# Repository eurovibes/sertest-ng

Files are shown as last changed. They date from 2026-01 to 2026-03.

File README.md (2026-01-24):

<!-- SPDX-FileCopyrightText: 2025 Benedikt Spranger <b.spranger@linutronix.de> -->
<!-- SPDX-License-Identifier: CERN-OHL-S-2.0 -->




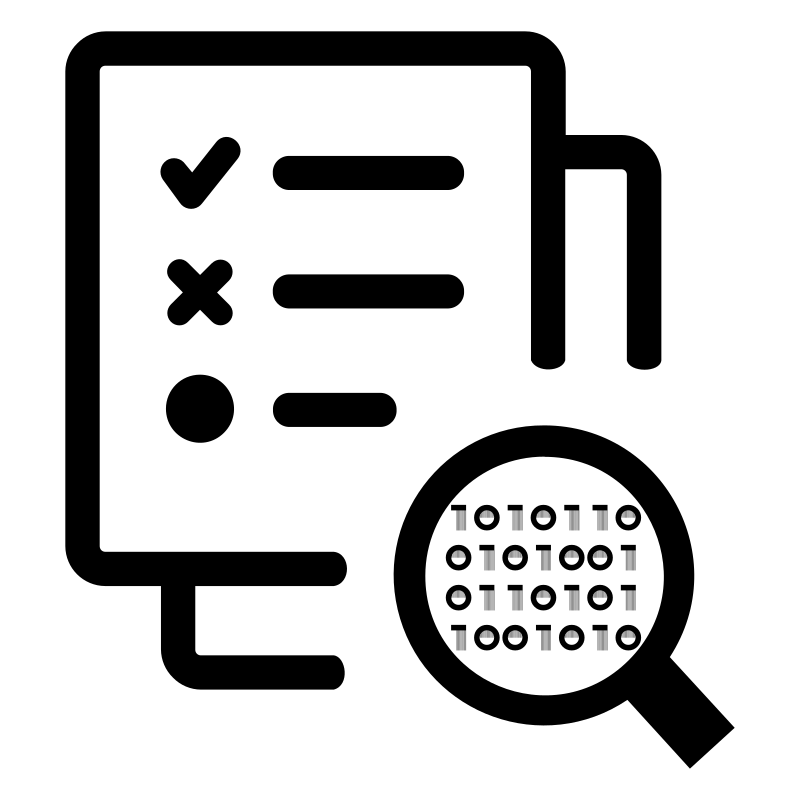
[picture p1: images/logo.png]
sertest-ng logo


# sertest-ng - A swiss knife serial testing tool

Serial interfaces like RS-232, RS-422/485 or CAN bus are even used in this
modern times. While reworking the 8250 driver in the Linux kernel jogness
faced plethora of nasty hardware dedication with modern serial hardware.
Single tasks overtop the banks in getting functional hardware. This sucks
and reliable full featured serial testing hardwaare is needed.

sertest-ng tries to fill that gap. It has a USB interface to control a
CAN/CAN-FD bus interface, a full featured RS-232 interface and a RS-422/485
interface. On top a RX/TX only RS-232 is equipped.

## License rules

sertest-ng is provided under the terms of the CERN-OHL-S license version 2 as
provided in the LICENSES/CERN-OHL-S-2.0 file.

Instead of adding license boilerplates to the individual files, sertest-ng uses
SPDX license identifiers, which are machine parseable and considered legaly
equivalent.

The SPDX license identifier in sertest-ng shall be added at the first possible
line in a file which can contain a comment. This is normally the first line
except for scripts. Scripts require the #!PATH_TO_INTERPRETER tag in the
first line; place the SPDX identifier into the second line.

The SPDX license identifier is added in form of a comment.

## Copyright and License
Copyright Benedikt Spranger 2025.
This source describes Open Hardware and is licensed under the CERNOHL-S v2.
You may redistribute and modify this source and make products using it
under the terms of the CERN-OHL-S v2
(https://ohwr.org/cern ohl_s_v2.txt).
This source is distributed WITHOUT ANY EXPRESS OR IMPLIED
WARRANTY, INCLUDING OF MERCHANTABILITY, SATISFACTORY
QUALITY AND FITNESS FOR A PARTICULAR PURPOSE. Please see
the CERN-OHL-S v2 for applicable conditions.
Source location: https://github.com/eurovibes/sertest-ng
As per CERN-OHL-S v2 section 4, should You produce hardware based
on this source, You must where practicable maintain the Source Location
visible on the external case of the sertest-ng or other products you make using
this source.

# Dedication
This hardware is dedicated to the great Linux Kernel Crew at Linutronix (https://www.linutronix.de)

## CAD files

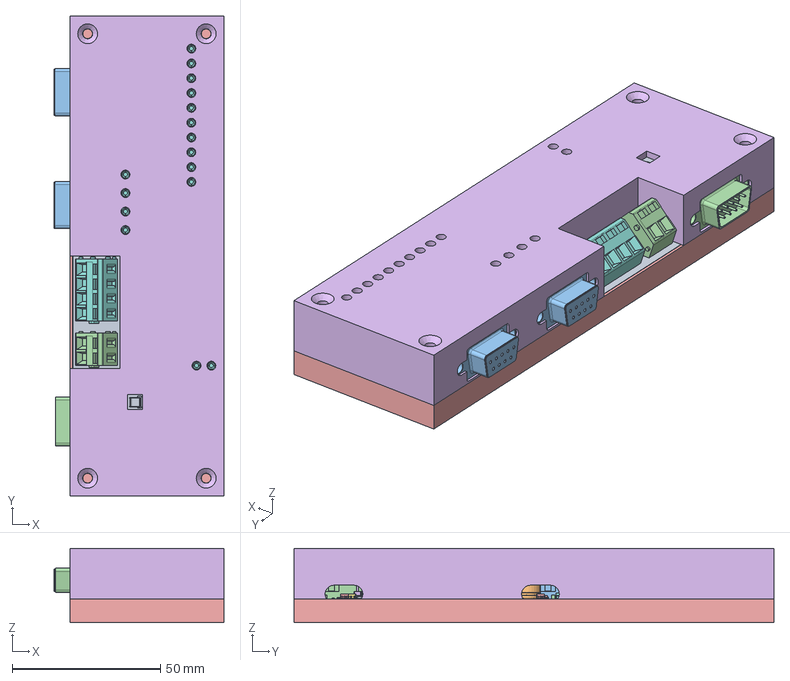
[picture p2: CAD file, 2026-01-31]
enclosure/sertest-ng.FCStd
57.3 x 162.0 x 25.0 mm
Pcb_c90
R209_R_0402_1005Metric_71b30412e50a x 52
SW101_SW_PUSH_6mm_52e52971358b
U202_TSSOP-24_4.4x7.8mm_P0.65mm_9c6549b88e3d
U303_SOT-23-6_ea51964c7aec x 2
D106_LED_0603_1608Metric_be7acdb3c4a0 x 6
C201_C_0402_1005Metric_272abea8df1f x 23
D211_AAA3528_c9d753128b57 x 16
R102_R_1206_3216Metric_2003ceb36cc6 x 3
U201_SSOP-28_5.3x10.2mm_P0.65mm_6feaa2b9f8e5
U103_LQFP-64_10x10mm_P0.5mm_cab5baf1425d
FB401_L_0805_2012Metric_7463febe9e80 x 6
D101_D_SOD-323_47d894987f89
U102_SOT-223_5101afb0bdb3
Y102_Crystal_SMD_3215-2Pin_3.2x1.5mm_ec3cd09e3611
J203_236-404_e90f42bb17cb
C302_C_0603_1608Metric_b7eb0275197c x 2
C110_C_0805_2012Metric_42e2c4361067 x 3
J201_DSUB-9_Socket_Horizontal_P2.77x2.84mm_EdgePinOffset4.94mm_Housed_ MountingHolesOffset4.94mm_27f627229b8b x 2
J401_DSUB-9_Pins_Horizontal_P2.77x2.84mm_EdgePinOffset4.94mm_Housed_ MountingHolesOffset4.94mm_41fe26cd4ce2
U101_SOIC-8_3.9x4.9mm_P1.27mm_d6df2d891575 x 2
JP403_PinHeader_1x02_P254mm_Vertical_ba5a3424f0d6
U302_JEITA_SOIC-8_3.9x4.9mm_P1.27mm_1356cbc908f0
U301_SOT-23-3_202f0379b9ee
SW401_TL2202xxYA_989cfd24e9e1
C106_CP_Radial_D80mm_P350mm_9079e7fa1cdd
Y101_Crystal_SMD_5032-2Pin_5.0x3.2mm_d8392e121ffc
J402_236-402_7fcaa99cd5cf
bottom
top

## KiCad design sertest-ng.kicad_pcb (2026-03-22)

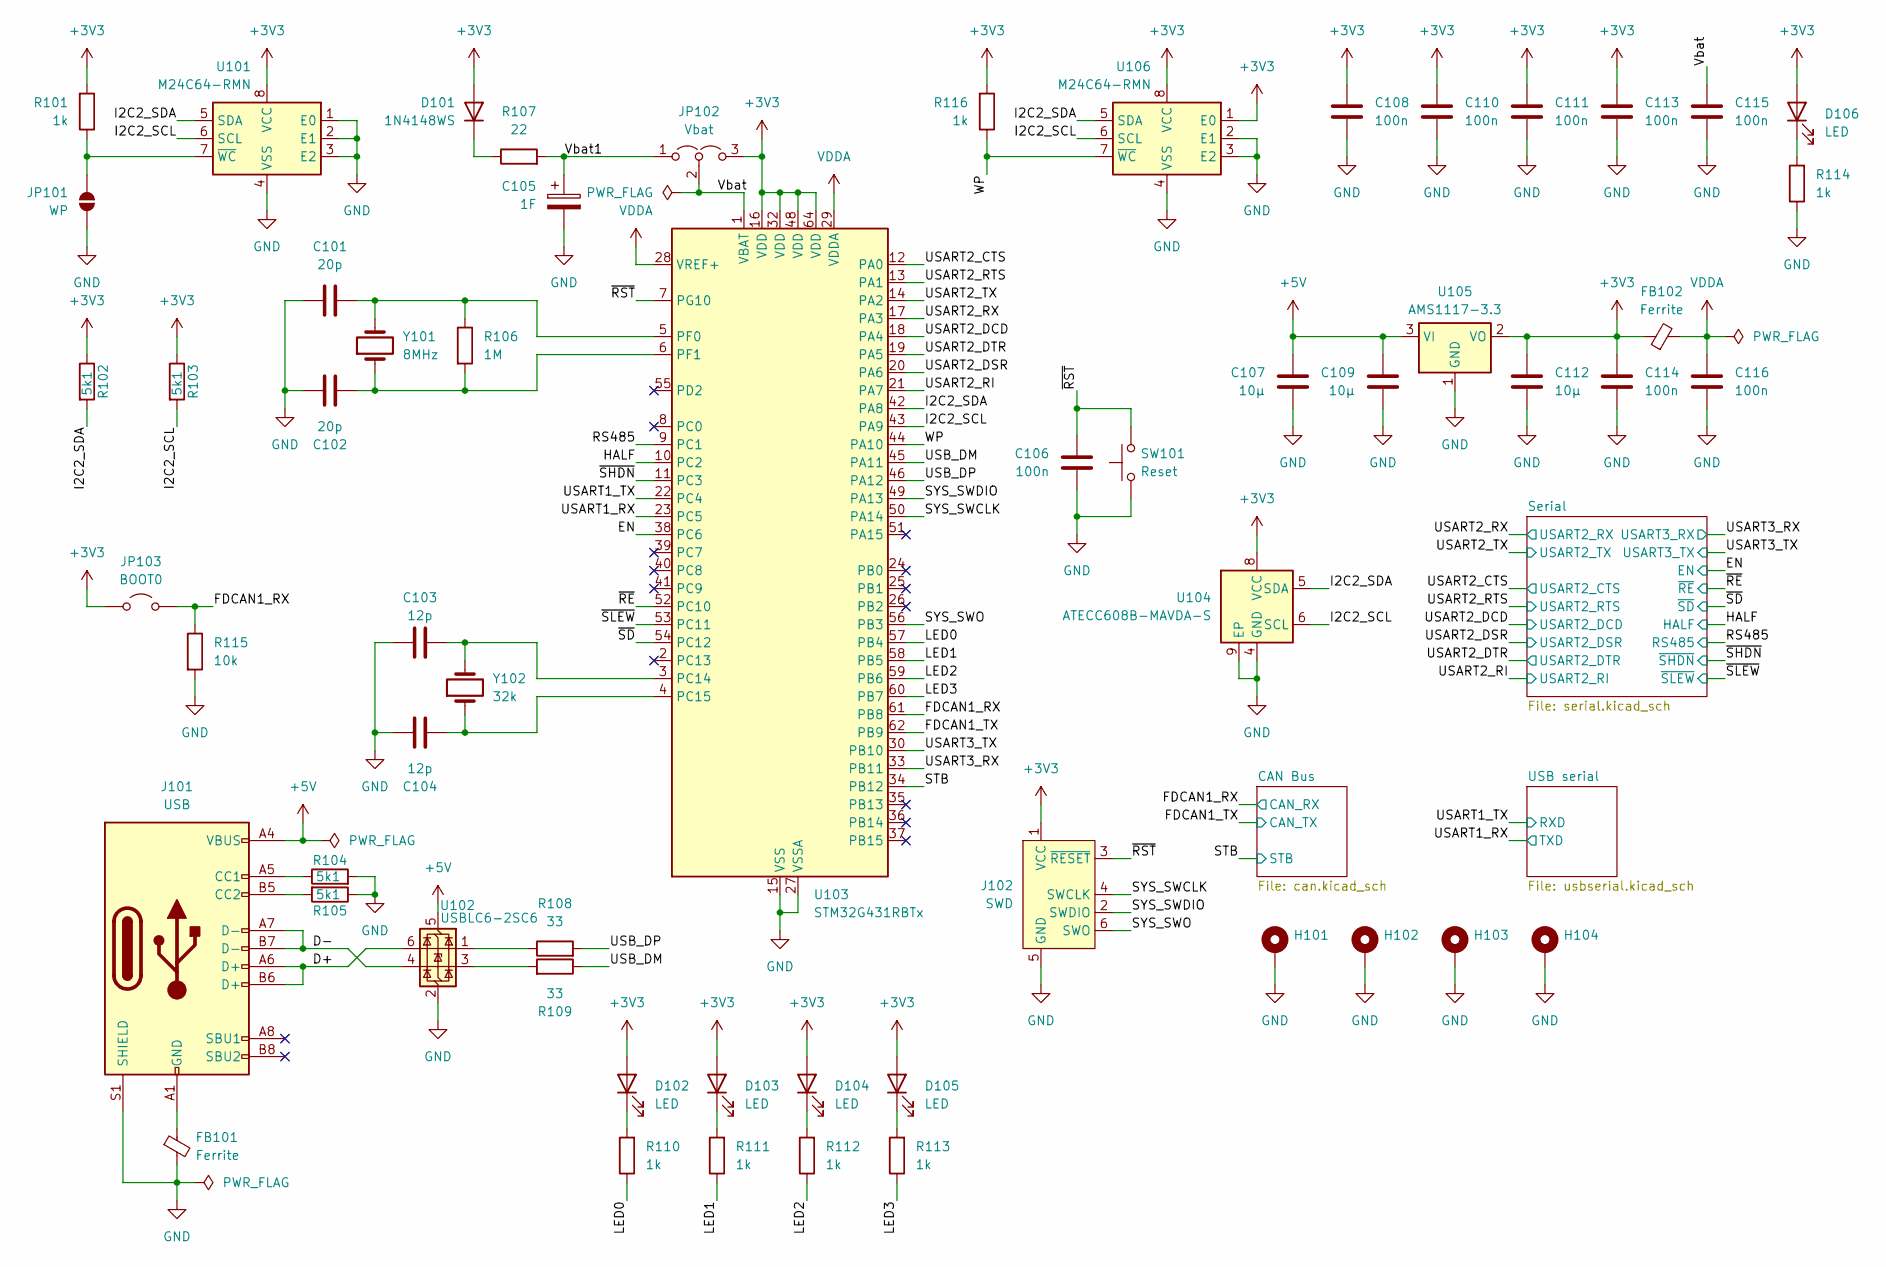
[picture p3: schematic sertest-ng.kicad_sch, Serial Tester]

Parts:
C101, C102: 20p; C_0402_1005Metric; lcsc# C1554
C103, C104: 12p; C_0402_1005Metric; lcsc# C1547
C105: 1F; CP_Radial_D8.0mm_P3.50mm
C106: 100n; C_0402_1005Metric; mpn CL05B104KB54PNC; LCSC# C307331
C107, C109, C112: 10µ; C_0805_2012Metric; lcsc# C15850
C108, C110, C111, C113, C114, C115, C116: 100n; C_0402_1005Metric; lcsc# C307331
D101: 1N4148WS; D_SOD-323; lcsc# C2128
D102, D103, D104, D105, D106: LED; LED_0603_1608Metric; mpn KT-0603R; LCSC# C2286
FB101: Ferrite; L_0805_2012Metric; mpn GZ1608D601TF; LCSC# C1002
FB102: Ferrite; L_0805_2012Metric; lcsc# C1015
H101, H102, H103, H104: MountingHole_3.2mm_M3_ISO14580_Pad; mpn N/A
J101: USB; USB_C_Receptacle_G-Switch_GT-USB-7010ASV; lcsc# C2988369
J102: SWD; Tag-Connect_TC2030-IDC-FP_2x03_P1.27mm_Vertical
JP101: WP; SolderJumper-2_P1.3mm_Open_Pad1.0x1.5mm
JP102: Vbat; SolderJumper-3_P1.3mm_Open_Pad1.0x1.5mm
JP103: BOOT0; SolderJumper-2_P1.3mm_Open_Pad1.0x1.5mm
R101, R110, R111, R112, R113, R114, R116: 1k; R_0402_1005Metric; mpn 0402WGF1001TCE; LCSC# C11702
R102, R103, R104, R105: 5k1; R_0402_1005Metric; lcsc# C25905
R106: 1M; R_0402_1005Metric; lcsc# C26083
R107: 22; R_1206_3216Metric; lcsc# C17958
R108, R109: 33; R_0402_1005Metric; lcsc# C25105
R115: 10k; R_0402_1005Metric; lcsc# C25744
SW101: Reset; SW_PUSH_6mm; mpn TACT-65R-F
U101, U106: M24C64-RMN; SOIC-8_3.9x4.9mm_P1.27mm; lcsc# C79988
U102: USBLC6-2SC6; SOT-23-6; mpn USBLC6-2SC6; LCSC# C2827654
U103: STM32G431RBTx; LQFP-64_10x10mm_P0.5mm; lcsc# C431633
U104: ATECC608B-MAVDA-S; DFN-8-1EP_3x2mm_P0.5mm_EP1.3x1.5mm; mpn ATECC608B-MAVDA-S; LCSC# C17350254
U105: AMS1117-3.3; SOT-223-3_TabPin2; lcsc# C6186
Y101: 8MHz; Crystal_SMD_5032-2Pin_5.0x3.2mm; lcsc# C115962
Y102: 32k; Crystal_SMD_3215-2Pin_3.2x1.5mm; lcsc# C32346

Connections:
+3V3: C108.1, C110.1, C111.1, C112.1, C113.1, C114.1, D101.2 (A), D102.2 (A), D103.2 (A), D104.2 (A), D105.2 (A), D106.2 (A), FB102.1, J102.1 (VCC), JP102.3 (B), JP103.1 (A), R101.2, R102.1, R103.1, R116.2, U101.8 (VCC), U103.16 (VDD), U103.32 (VDD), U103.48 (VDD), U103.64 (VDD), U104.8 (VCC), U105.2 (VO), U106.1 (E0), U106.8 (VCC); also elsewhere on the board
+5V: C107.1, C109.1, J101.A4 (VBUS), J101.A9 (VBUS), J101.B4 (VBUS), J101.B9 (VBUS), U102.5 (VBUS), U105.3 (VI)
/D+: J101.A6 (D+), J101.B6 (D+), U102.6 (I/O1)
/D-: J101.A7 (D-), J101.B7 (D-), U102.4 (I/O2)
/EN: U103.38 (PC6); also elsewhere on the board
/FDCAN1_RX: JP103.2 (B), R115.1, U103.61 (PB8); also elsewhere on the board
/FDCAN1_TX: U103.62 (PB9); also elsewhere on the board
/HALF: U103.10 (PC2); also elsewhere on the board
/I2C2_SCL: R103.2, U101.6 (SCL), U103.43 (PA9), U104.6 (SCL), U106.6 (SCL)
/I2C2_SDA: R102.2, U101.5 (SDA), U103.42 (PA8), U104.5 (SDA), U106.5 (SDA)
/LED0: R110.1, U103.57 (PB4)
/LED1: R111.1, U103.58 (PB5)
/LED2: R112.1, U103.59 (PB6)
/LED3: R113.1, U103.60 (PB7)
/RS485: U103.9 (PC1); also elsewhere on the board
/STB: U103.34 (PB12); also elsewhere on the board
/SYS_SWCLK: J102.4 (SWCLK), U103.50 (PA14)
/SYS_SWDIO: J102.2 (SWDIO), U103.49 (PA13)
/SYS_SWO: J102.6 (SWO), U103.56 (PB3)
/USART1_RX: U103.23 (PC5); also elsewhere on the board
/USART1_TX: U103.22 (PC4); also elsewhere on the board
/USART2_CTS: U103.12 (PA0); also elsewhere on the board
/USART2_DCD: U103.18 (PA4); also elsewhere on the board
/USART2_DSR: U103.20 (PA6); also elsewhere on the board
/USART2_DTR: U103.19 (PA5); also elsewhere on the board
/USART2_RI: U103.21 (PA7); also elsewhere on the board
/USART2_RTS: U103.13 (PA1); also elsewhere on the board
/USART2_RX: U103.17 (PA3); also elsewhere on the board
/USART2_TX: U103.14 (PA2); also elsewhere on the board
/USART3_RX: U103.33 (PB11); also elsewhere on the board
/USART3_TX: U103.30 (PB10); also elsewhere on the board
/USB_DM: R109.1, U103.45 (PA11)
/USB_DP: R108.2, U103.46 (PA12)
/Vbat: C115.1, JP102.2 (C), U103.1 (VBAT)
/Vbat1: C105.1, JP102.1 (A), R107.2
/WP: R116.1, U103.44 (PA10), U106.7 (~WC)
/~RE: U103.52 (PC10); also elsewhere on the board
/~RST: C106.1, J102.3 (~RESET), SW101.2, U103.7 (PG10)
/~SD: U103.54 (PC12); also elsewhere on the board
/~SHDN: U103.11 (PC3); also elsewhere on the board
/~SLEW: U103.53 (PC11); also elsewhere on the board
GND: C101.1, C102.1, C103.1, C104.1, C105.2, C106.2, C107.2, C108.2, C109.2, C110.2, C111.2, C112.2, C113.2, C114.2, C115.2, C116.2, FB101.2, H101.1, H102.1, H103.1, H104.1, J101.S1 (SHIELD), J102.5 (GND), JP101.1 (A), R104.2, R105.1, R114.1, R115.2, SW101.1, U101.1 (E0), U101.2 (E1), U101.3 (E2), U101.4 (VSS), U102.2 (GND), U103.15 (VSS), U103.27 (VSSA), U103.31 (VSS), U103.47 (VSS), U103.63 (VSS), U104.4 (GND), U104.9 (EP), U105.1 (GND), U106.2 (E1), U106.3 (E2), U106.4 (VSS); also elsewhere on the board
unnamed: D101.1 (K), R107.1
unnamed: D102.1 (K), R110.2
unnamed: D103.1 (K), R111.2
unnamed: D104.1 (K), R112.2
unnamed: D105.1 (K), R113.2
unnamed: D106.1 (K), R114.2
unnamed: FB101.1, J101.A1 (GND), J101.A12 (GND), J101.B1 (GND), J101.B12 (GND)
unnamed: J101.A5 (CC1), R104.1
unnamed: J101.B5 (CC2), R105.2
unnamed: JP101.2 (B), R101.1, U101.7 (~WC)
unnamed: R108.1, U102.1 (I/O1)
unnamed: R109.2, U102.3 (I/O2)
unnamed: C103.2, U103.3 (PC14), Y102.2
unnamed: C104.2, U103.4 (PC15), Y102.1
unnamed: C101.2, R106.1, U103.5 (PF0), Y101.2
unnamed: C102.2, R106.2, U103.6 (PF1), Y101.1
VDDA: C116.1, FB102.2, U103.28 (VREF+), U103.29 (VDDA)

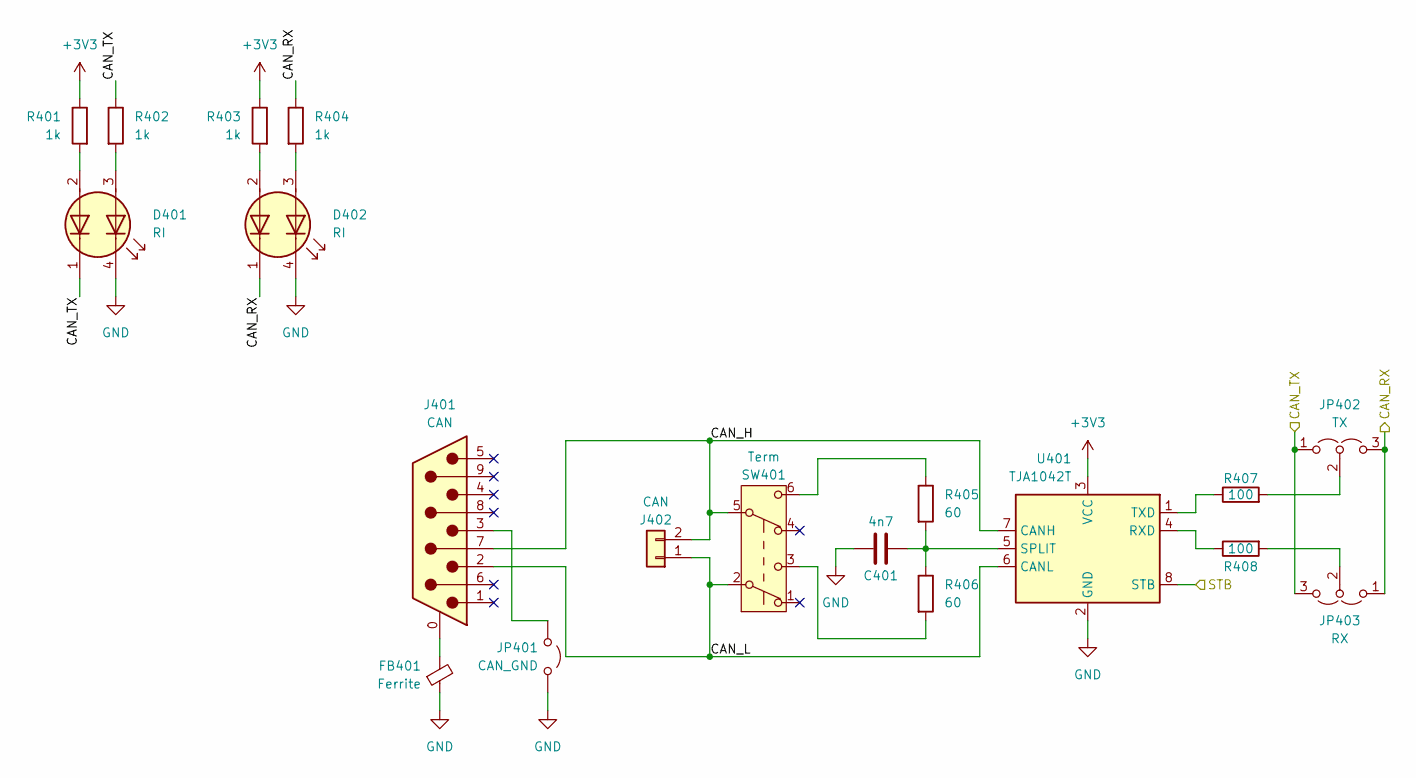
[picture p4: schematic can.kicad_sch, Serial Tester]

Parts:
C401: 4n7; C_0402_1005Metric; mpn 0402B472K500NT; LCSC# C1538
D401, D402: RI; LED_Kingbright_AAA3528ESGCT; lcsc# C601701
FB401: Ferrite; L_0805_2012Metric; lcsc# C1015
J401: CAN; DSUB-9_Pins_Horizontal_P2.77x2.84mm_EdgePinOffset4.94mm_Hou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
J402: CAN; TerminalBlock_WAGO_236-402_1x02_P5.00mm_45Degree; mpn 236-402; Digikey# 2946-236-402-ND
JP401: CAN_GND; PinHeader_1x02_P2.54mm_Vertical
JP402: TX; SolderJumper-3_P1.3mm_Open_Pad1.0x1.5mm
JP403: RX; SolderJumper-3_P1.3mm_Open_Pad1.0x1.5mm
R401, R402, R403, R404: 1k; R_0402_1005Metric; lcsc# C11702
R405, R406: 60; R_1206_3216Metric; mpn 1206W4F604JT5E; LCSC# C57572
R407, R408: 100; R_0402_1005Metric; mpn 0402WGF1000TCE; LCSC# C25076
SW401: Term; SW_Push_2P2T_Toggle_CK_PVA2xxH1xxxxxxV2; mpn TL2202EEZB (GRN ACT); Digikey# 141-TL2202EEZB(GRNACT)-ND
U401: TJA1042T; SOIC-8_3.9x4.9mm_P1.27mm; mpn TJA1042T/1J; LCSC# C53670

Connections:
+3V3: R401.1, R403.1, U401.3 (VCC); also elsewhere on the board
/CAN Bus/CAN_H: J401.7, J402.2, SW401.5 (B), U401.7 (CANH)
/CAN Bus/CAN_L: J401.2, J402.1, SW401.2 (B), U401.6 (CANL)
/FDCAN1_RX: D402.1 (K2), JP402.3 (B), JP403.1 (A), R404.1; also elsewhere on the board
/FDCAN1_TX: D401.1 (K2), JP402.1 (A), JP403.3 (B), R402.1; also elsewhere on the board
/STB: U401.8 (STB); also elsewhere on the board
GND: C401.1, D401.4 (K1), D402.4 (K1), FB401.1, JP401.1 (A), U401.2 (GND); also elsewhere on the board
unnamed: D401.3 (A1), R402.2
unnamed: D401.2 (A2), R401.2
unnamed: D402.3 (A1), R404.2
unnamed: D402.2 (A2), R403.2
unnamed: FB401.2, J401.0 (PAD)
unnamed: J401.3, JP401.2 (B)
unnamed: JP402.2 (C), R407.2
unnamed: JP403.2 (C), R408.2
unnamed: R405.1, SW401.6 (C)
unnamed: R406.2, SW401.3 (C)
unnamed: R408.1, U401.4 (RXD)
unnamed: C401.2, R405.2, R406.1, U401.5 (SPLIT)
unnamed: R407.1, U401.1 (TXD)

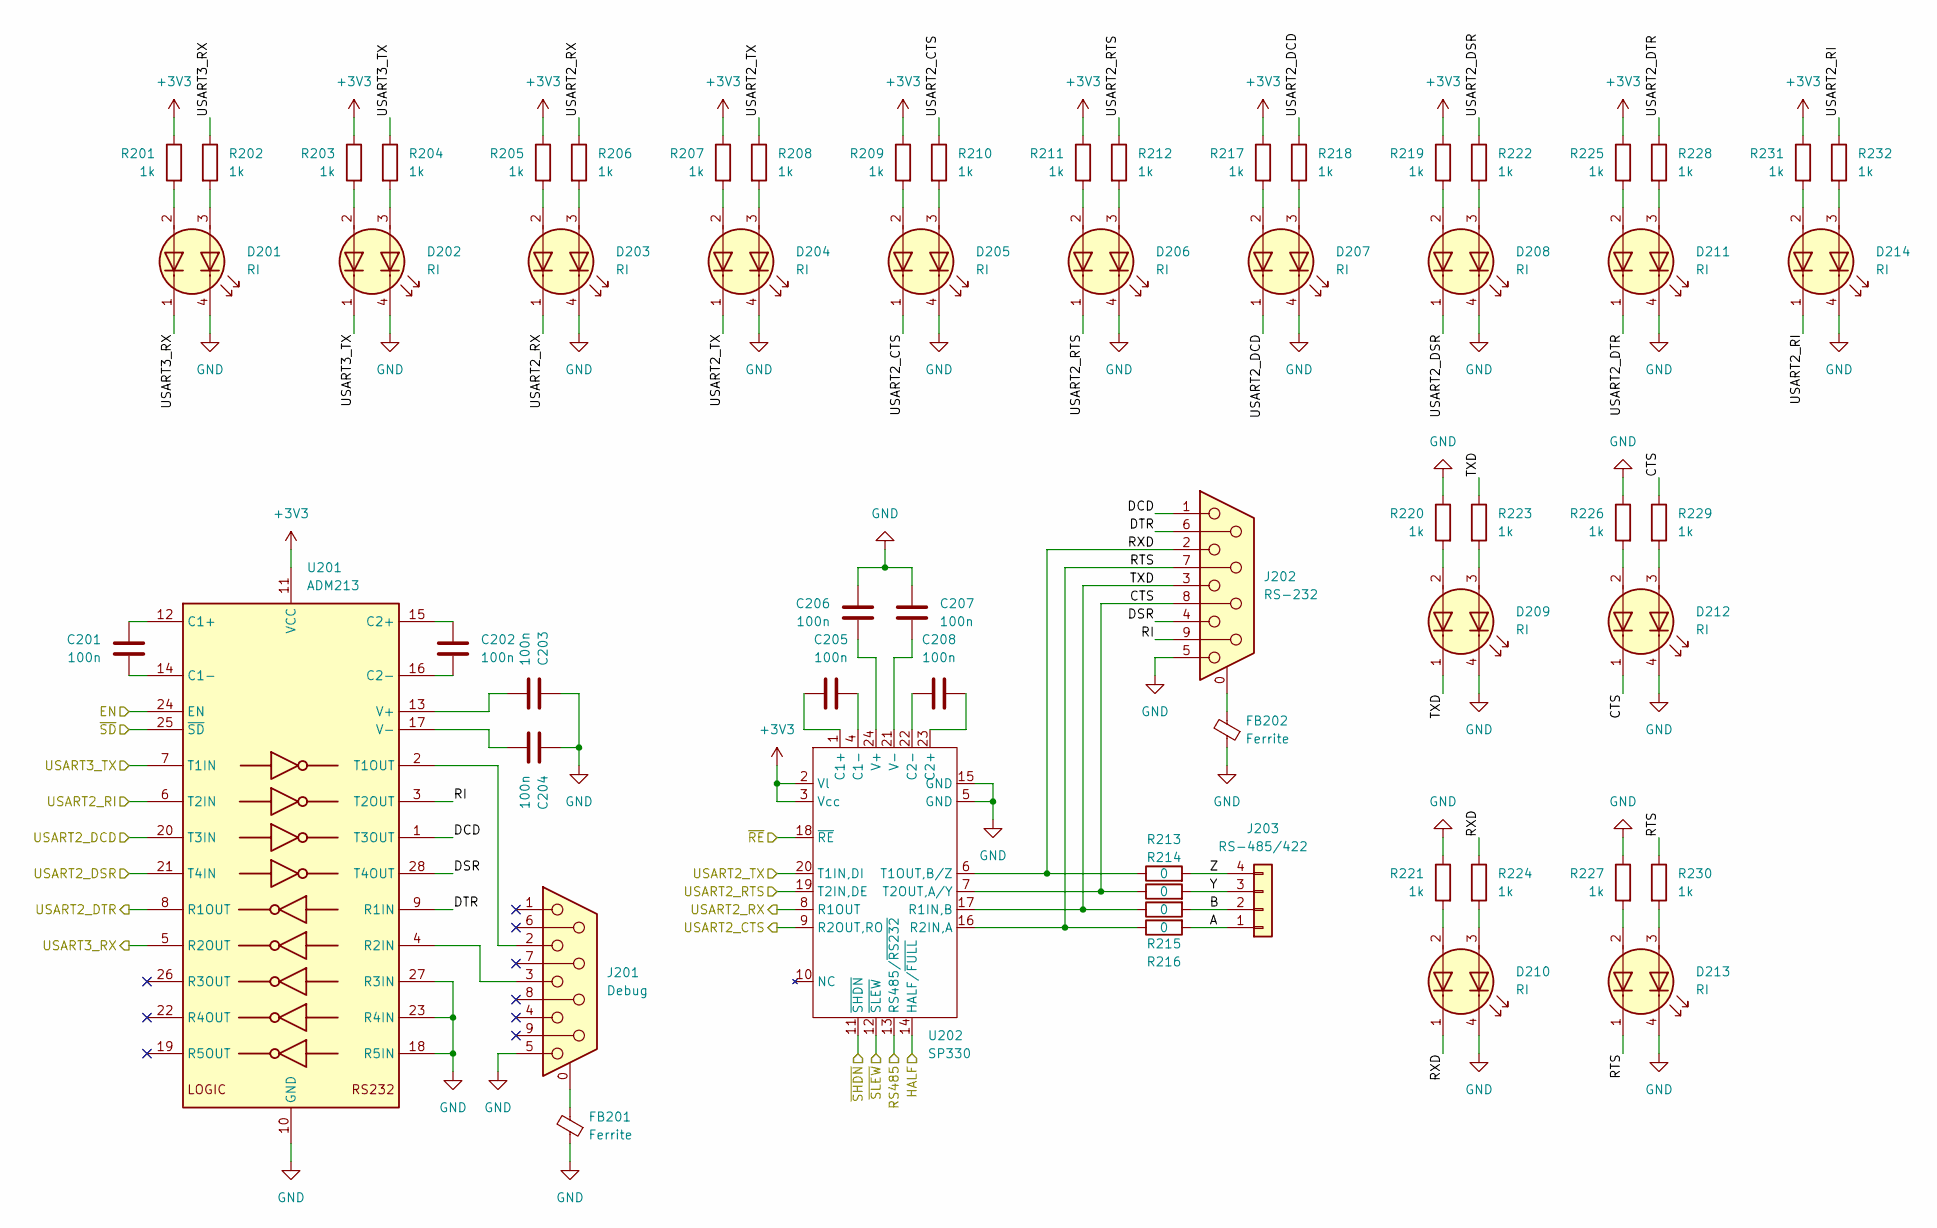
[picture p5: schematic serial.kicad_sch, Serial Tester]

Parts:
C201, C202, C203, C204, C205, C206, C207, C208: 100n; C_0402_1005Metric; lcsc# C307331
D201, D202, D203, D204, D205, D206, D207, D208, D209, D210, D211, D212, D213, D214: RI; LED_Kingbright_AAA3528ESGCT; lcsc# C601701
FB201, FB202: Ferrite; L_0805_2012Metric; lcsc# C1015
J201: Debug; DSUB-9_Socket_Horizontal_P2.77x2.84mm_EdgePinOffset4.94mm_H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
J202: RS-232; DSUB-9_Socket_Horizontal_P2.77x2.84mm_EdgePinOffset4.94mm_H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
J203: RS-485/422; TerminalBlock_WAGO_236-404_1x04_P5.00mm_45Degree
R201, R202, R203, R204, R205, R206, R207, R208, R209, R210, R211, R212, R217, R218, R219, R220, R221, R222, R223, R224, R225, R226, R227, R228, R229, R230, R231, R232: 1k; R_0402_1005Metric; lcsc# C11702
R213, R214, R215, R216: 0; R_0402_1005Metric; lcsc# C17168
U201: ADM213; SSOP-28_5.3x10.2mm_P0.65mm; lcsc# C415725
U202: SP330; TSSOP-24_4.4x7.8mm_P0.65mm; lcsc# C916084

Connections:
+3V3: R201.1, R203.1, R205.1, R207.1, R209.1, R211.1, R217.1, R219.1, R225.1, R231.1, U201.11 (VCC), U202.2 (Vl), U202.3 (Vcc); also elsewhere on the board
/EN: U201.24 (EN); also elsewhere on the board
/HALF: U202.14 (HALF/~FULL); also elsewhere on the board
/RS485: U202.13 (RS485/~RS232); also elsewhere on the board
/Serial/A: J203.1, R216.2
/Serial/B: J203.2, R215.2
/Serial/CTS: D212.1 (K2), J202.8, R214.1, R229.1, U202.7 (T2OUT,A/Y)
/Serial/DCD: J202.1, U201.1 (T3OUT)
/Serial/DSR: J202.4, U201.28 (T4OUT)
/Serial/DTR: J202.6, U201.9 (R1IN)
/Serial/RI: J202.9, U201.3 (T2OUT)
/Serial/RTS: D213.1 (K2), J202.7, R216.1, R230.1, U202.16 (R2IN,A)
/Serial/RXD: D210.1 (K2), J202.2, R213.1, R224.1, U202.6 (T1OUT,B/Z)
/Serial/TXD: D209.1 (K2), J202.3, R215.1, R223.1, U202.17 (R1IN,B)
/Serial/Y: J203.3, R214.2
/Serial/Z: J203.4, R213.2
/USART2_CTS: D205.1 (K2), R210.1, U202.9 (R2OUT,RO); also elsewhere on the board
/USART2_DCD: D207.1 (K2), R218.1, U201.20 (T3IN); also elsewhere on the board
/USART2_DSR: D208.1 (K2), R222.1, U201.21 (T4IN); also elsewhere on the board
/USART2_DTR: D211.1 (K2), R228.1, U201.8 (R1OUT); also elsewhere on the board
/USART2_RI: D214.1 (K2), R232.1, U201.6 (T2IN); also elsewhere on the board
/USART2_RTS: D206.1 (K2), R212.1, U202.19 (T2IN,DE); also elsewhere on the board
/USART2_RX: D203.1 (K2), R206.1, U202.8 (R1OUT); also elsewhere on the board
/USART2_TX: D204.1 (K2), R208.1, U202.20 (T1IN,DI); also elsewhere on the board
/USART3_RX: D201.1 (K2), R202.1, U201.5 (R2OUT); also elsewhere on the board
/USART3_TX: D202.1 (K2), R204.1, U201.7 (T1IN); also elsewhere on the board
/~RE: U202.18 (~RE); also elsewhere on the board
/~SD: U201.25 (~SD); also elsewhere on the board
/~SHDN: U202.11 (~SHDN); also elsewhere on the board
/~SLEW: U202.12 (~SLEW); also elsewhere on the board
GND: C203.2, C204.2, C206.2, C207.2, D201.4 (K1), D202.4 (K1), D203.4 (K1), D204.4 (K1), D205.4 (K1), D206.4 (K1), D207.4 (K1), D208.4 (K1), D209.4 (K1), D210.4 (K1), D211.4 (K1), D212.4 (K1), D213.4 (K1), D214.4 (K1), FB201.1, FB202.1, J201.5, J202.5, R220.1, R221.1, R226.1, R227.1, U201.10 (GND), U201.18 (R5IN), U201.23 (R4IN), U201.27 (R3IN), U202.5 (GND), U202.15 (GND); also elsewhere on the board
unnamed: D201.3 (A1), R202.2
unnamed: D201.2 (A2), R201.2
unnamed: D202.3 (A1), R204.2
unnamed: D202.2 (A2), R203.2
unnamed: D203.3 (A1), R206.2
unnamed: D203.2 (A2), R205.2
unnamed: D204.3 (A1), R208.2
unnamed: D204.2 (A2), R207.2
unnamed: D205.3 (A1), R210.2
unnamed: D205.2 (A2), R209.2
unnamed: D206.3 (A1), R212.2
unnamed: D206.2 (A2), R211.2
unnamed: D207.3 (A1), R218.2
unnamed: D207.2 (A2), R217.2
unnamed: D208.3 (A1), R222.2
unnamed: D208.2 (A2), R219.2
unnamed: D209.3 (A1), R223.2
unnamed: D209.2 (A2), R220.2
unnamed: D210.3 (A1), R224.2
unnamed: D210.2 (A2), R221.2
unnamed: D211.3 (A1), R228.2
unnamed: D211.2 (A2), R225.2
unnamed: D212.3 (A1), R229.2
unnamed: D212.2 (A2), R226.2
unnamed: D213.3 (A1), R230.2
unnamed: D213.2 (A2), R227.2
unnamed: D214.3 (A1), R232.2
unnamed: D214.2 (A2), R231.2
unnamed: FB201.2, J201.0 (PAD)
unnamed: FB202.2, J202.0 (PAD)
unnamed: C201.2, U201.12 (C1+)
unnamed: C201.1, U201.14 (C1-)
unnamed: C202.2, U201.15 (C2+)
unnamed: C202.1, U201.16 (C2-)
unnamed: J201.3, U201.4 (R2IN)
unnamed: J201.2, U201.2 (T1OUT)
unnamed: C203.1, U201.13 (V+)
unnamed: C204.1, U201.17 (V-)
unnamed: C205.1, U202.1 (C1+)
unnamed: C205.2, U202.4 (C1-)
unnamed: C208.2, U202.23 (C2+)
unnamed: C208.1, U202.22 (C2-)
unnamed: C206.1, U202.24 (V+)
unnamed: C207.1, U202.21 (V-)

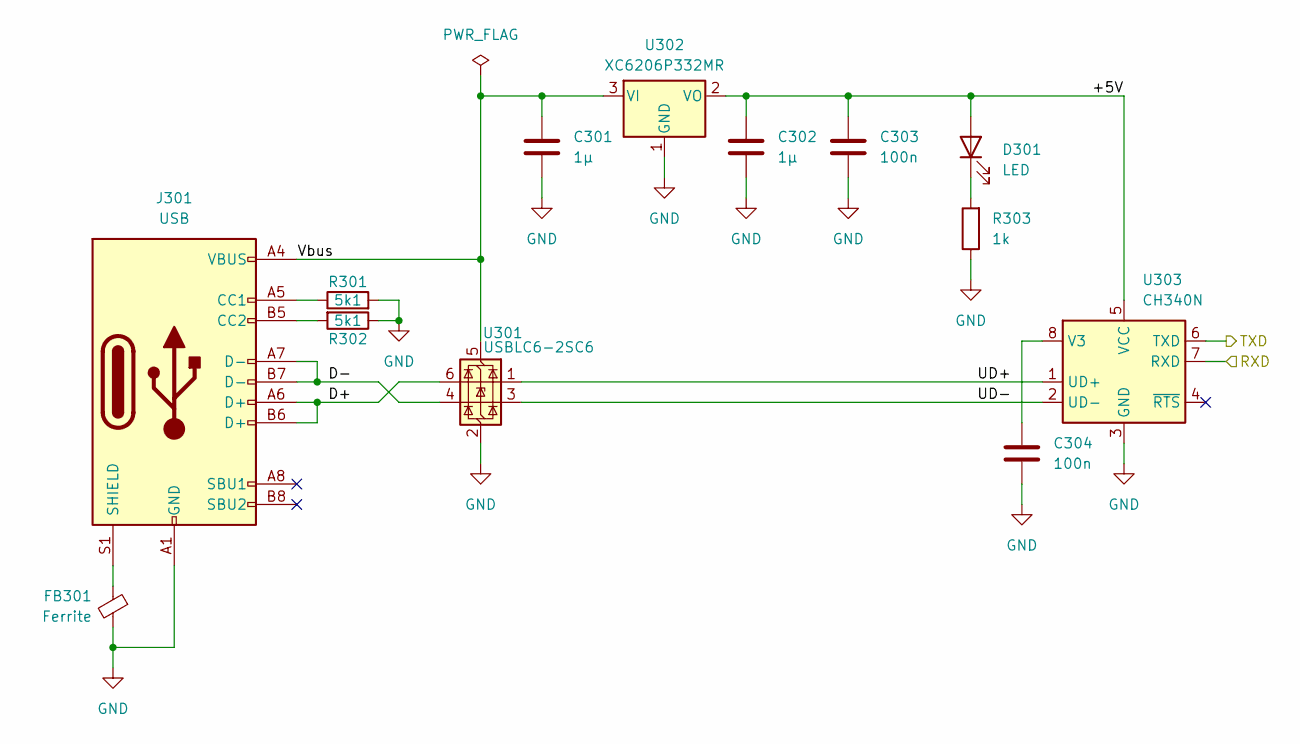
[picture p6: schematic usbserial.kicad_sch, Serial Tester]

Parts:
C301, C302: 1µ; C_0603_1608Metric; mpn CL10A105KB8NNNC; LCSC# C15849
C303, C304: 100n; C_0402_1005Metric; mpn CL05B104KB54PNC; LCSC# C307331
D301: LED; LED_0603_1608Metric; mpn KT-0603R; LCSC# C2286
FB301: Ferrite; L_0805_2012Metric; mpn GZ1608D601TF; LCSC# C1002
J301: USB; USB_C_Receptacle_G-Switch_GT-USB-7010ASV; lcsc# C2988369
R301, R302: 5k1; R_0402_1005Metric; lcsc# C25905
R303: 1k; R_0402_1005Metric; mpn 0402WGF1001TCE; LCSC# C11702
U301: USBLC6-2SC6; SOT-23-6; mpn USBLC6-2SC6; LCSC# C2827654
U302: XC6206P332MR; SOT-23-3; mpn XC6206P332MR-G; LCSC# C5446
U303: CH340N; JEITA_SOIC-8_3.9x4.9mm_P1.27mm; mpn CH340N; LCSC# C2977777

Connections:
/USART1_RX: U303.6 (TXD); also elsewhere on the board
/USART1_TX: U303.7 (RXD); also elsewhere on the board
/USB serial/+5V: C302.1, C303.1, D301.2 (A), U302.2 (VO), U303.5 (VCC)
/USB serial/D+: J301.A6 (D+), J301.B6 (D+), U301.6 (I/O1)
/USB serial/D-: J301.A7 (D-), J301.B7 (D-), U301.4 (I/O2)
/USB serial/UD+: U301.1 (I/O1), U303.1 (UD+)
/USB serial/UD-: U301.3 (I/O2), U303.2 (UD-)
/USB serial/Vbus: C301.1, J301.A4 (VBUS), J301.A9 (VBUS), J301.B4 (VBUS), J301.B9 (VBUS), U301.5 (VBUS), U302.3 (VI)
GND: C301.2, C302.2, C303.2, C304.2, FB301.2, J301.A1 (GND), J301.A12 (GND), J301.B1 (GND), J301.B12 (GND), R301.2, R302.1, R303.1, U301.2 (GND), U302.1 (GND), U303.3 (GND); also elsewhere on the board
unnamed: D301.1 (K), R303.2
unnamed: J301.A5 (CC1), R301.1
unnamed: J301.B5 (CC2), R302.2
unnamed: FB301.1, J301.S1 (SHIELD)
unnamed: C304.1, U303.8 (V3)

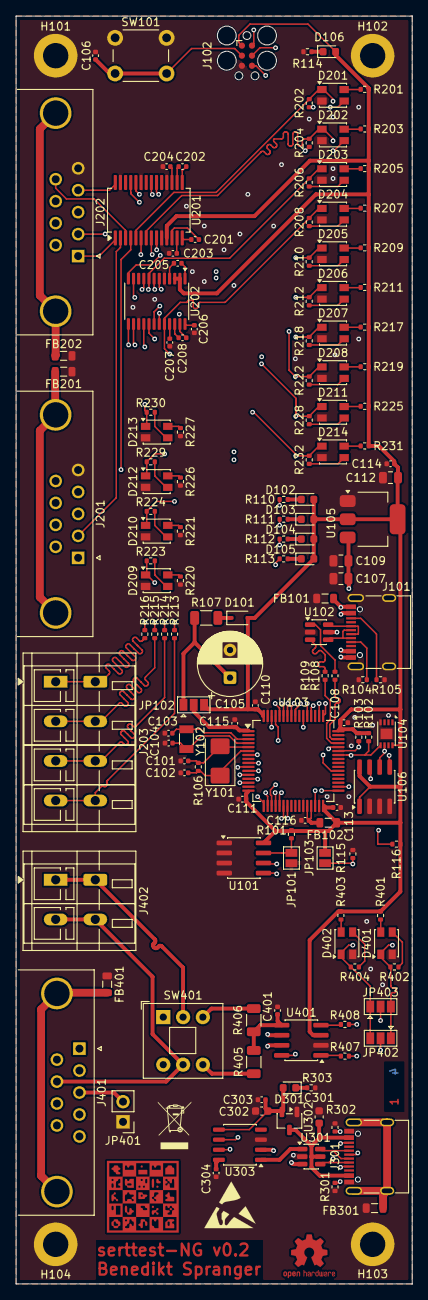
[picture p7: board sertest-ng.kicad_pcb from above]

Board: 4 copper layers, 50.0 x 160.0 mm, 151 parts (0 on the bottom side), 141 nets.

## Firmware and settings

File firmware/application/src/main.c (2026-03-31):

/*
 * Copyright (c) 2026 Benedikt Spranger
 * SPDX-License-Identifier: Apache-2.0
 */
#include <cryptoauthlib.h>

#include <zephyr/kernel.h>
#include <zephyr/device.h>
#include <zephyr/drivers/uart/uart_bridge.h>
#include <zephyr/logging/log.h>
#include <zephyr/logging/log_ctrl.h>
#include <zephyr/sys/util.h>

#include <app_version.h>

#include "sertest-ng.h"

LOG_MODULE_REGISTER(main, CONFIG_APP_LOG_LEVEL);

int main(void)
{
	struct rtc_time tm = {
		.tm_year = 2026 - 1900,
		.tm_mon = 3 - 1,
		.tm_mday = 17,
		.tm_hour = 2,
		.tm_min = 40,
		.tm_sec = 0,
	};

	uint8_t random_number[32], sn[ATCA_SERIAL_NUM_SIZE];
	ATCA_STATUS status;
	bool is_locked;

	printk("Eurovibes Sertest-NG Application %s\n", APP_VERSION_STRING);
	LOG_INIT();
	log_thread_set(k_current_get());

	if (usb_init()) {
		LOG_ERR("Failed to initialize USB device");
		return -ENODEV;
	}

	LOG_INF("USB device support enabled");
	k_sleep(K_MSEC(5000));

	if (get_type_plate()) {
		LOG_ERR("EEPROM device not ready");
		return -ENODEV;
	}

	cfg_ateccx08a_i2c_default.cfg_data = DEVICE_DT_NAME(DT_NODELABEL(i2c2));
	status = atcab_init(&cfg_ateccx08a_i2c_default);
	if (status != ATCA_SUCCESS)
	{
		LOG_ERR("atcab_init() failed: %02x", status);
		return -ENODEV;
	}

	status = atcab_is_locked(LOCK_ZONE_CONFIG, &is_locked);
	if (status != ATCA_SUCCESS)
	{
		LOG_ERR("failed to get lock status: %02x", status);
		//return -ENODEV;
	} else {
		LOG_INF("ATECC608 is %s", (is_locked) ? "locked" : "unlocked");
	}

	status = atcab_read_serial_number(sn);
	if (status != ATCA_SUCCESS)
	{
		LOG_ERR("failed to get serial number: %02x", status);
		//return -ENODEV;
	} else {
		uint32_t *d = (uint32_t *) sn;
		int i;

		for (i = 0; i < 8; i++)
			LOG_INF("Serial %d: 0x%08x", i, d[i]);
	}

	status = atcab_random(random_number);
	if (status != ATCA_SUCCESS)
	{
		LOG_ERR("failed to get random number: %02x", status);
		//return -ENODEV;
	} else {
		uint32_t *d = (uint32_t *) random_number;
		int i;

		for (i = 0; i < 8; i++)
			LOG_INF("Random %d: 0x%08x", i, d[i]);
	}

	if (rtc_init()) {
		LOG_ERR("RTC device is not ready");
		return -ENODEV;
	}

	LOG_INF("RTC device support enabled");

	set_date_time(&tm);

	while (1) {
		int ret;

		ret = get_date_time(&tm);
		if (ret)
			LOG_ERR("get_date_time() failed: %d", ret);
		k_sleep(K_MSEC(1000));
	}

	return 0;
}

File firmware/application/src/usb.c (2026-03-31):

/*
 * Copyright (c) 2026 Benedikt Spranger
 * SPDX-License-Identifier: Apache-2.0
 */

#include <zephyr/kernel.h>
#include <zephyr/device.h>
#include <zephyr/drivers/uart/uart_bridge.h>
#include <zephyr/logging/log.h>
#include <zephyr/usb/bos.h>
#include <zephyr/usb/msos_desc.h>
#include <zephyr/usb/usb_device.h>
#include <zephyr/usb/usbd.h>

#include <cannectivity/usb/class/gs_usb.h>

#include "sertest-ng.h"

#define USBD_VID	0xFFFF
#define USBD_PID	0xFFFF

LOG_MODULE_REGISTER(usb, CONFIG_APP_LOG_LEVEL);

#define DEVICE_DT_GET_COMMA(node_id) DEVICE_DT_GET(node_id),

static const char *const blocklist[] = {
	"dfu_dfu",
	NULL,
};

const struct device *uart_bridges[] = {
	DT_FOREACH_STATUS_OKAY(zephyr_uart_bridge, DEVICE_DT_GET_COMMA)
};

USBD_DEVICE_DEFINE(usbd_ctx, DEVICE_DT_GET(DT_NODELABEL(zephyr_udc0)),
		   USBD_VID, USBD_PID);

USBD_DESC_LANG_DEFINE(lang);
USBD_DESC_MANUFACTURER_DEFINE(mfr, "Eurovibes");
USBD_DESC_PRODUCT_DEFINE(product, "Sertest-NG");
USBD_DESC_SERIAL_NUMBER_DEFINE(sn);
USBD_DESC_CONFIG_DEFINE(fs_cfg_desc, "FS Configuration");

static const uint8_t attributes = 0; // USB_SCD_REMOTE_WAKEUP;
static struct usbd_context *usbd;

USBD_CONFIGURATION_DEFINE(fs_config, attributes, 50, &fs_cfg_desc);

static const struct usb_bos_capability_lpm bos_cap_lpm = {
	.bLength = sizeof(struct usb_bos_capability_lpm),
	.bDescriptorType = USB_DESC_DEVICE_CAPABILITY,
	.bDevCapabilityType = USB_BOS_CAPABILITY_EXTENSION,
	.bmAttributes = 0UL,
};
USBD_DESC_BOS_DEFINE(usbext, sizeof(bos_cap_lpm), &bos_cap_lpm);

struct cannectivity_msosv2_descriptor {
	struct msosv2_descriptor_set_header header;
	struct msosv2_compatible_id gs_usb_compatible_id;
	struct msosv2_guids_property gs_usb_guids_property;
	struct msosv2_vendor_revision gs_usb_vendor_revision;
} __packed;

#define COMPATIBLE_ID_WINUSB 'W', 'I', 'N', 'U', 'S', 'B', 0x00, 0x00

#define CANNECTIVITY_GS_USB_DEVICE_INTERFACE_GUID \
	'{', 0x00, 'B', 0x00, '2', 0x00, '4', 0x00, 'D', 0x00, '8', 0x00, \
	'3', 0x00, '7', 0x00, '9', 0x00, '-', 0x00, '2', 0x00, '3', 0x00, \
	'5', 0x00, 'F', 0x00, '-', 0x00, '4', 0x00, '8', 0x00, '5', 0x00, \
	'3', 0x00, '-', 0x00, '9', 0x00, '5', 0x00, 'E', 0x00, '7', 0x00, \
	'-', 0x00, '7', 0x00, '7', 0x00, '7', 0x00, '2', 0x00, '5', 0x00, \
	'1', 0x00, '6', 0x00, 'F', 0x00, 'A', 0x00, '2', 0x00, 'D', 0x00, \
	'5', 0x00, '}', 0x00, 0x00, 0x00

static const struct cannectivity_msosv2_descriptor msosv2_descriptor = {
	.header = {
		.wLength = sizeof(struct msosv2_descriptor_set_header),
		.wDescriptorType = MS_OS_20_SET_HEADER_DESCRIPTOR,
		/* Windows version (8.1) (0x06030000) */
		.dwWindowsVersion = 0x06030000,
		.wTotalLength = sizeof(struct cannectivity_msosv2_descriptor),
	},
	.gs_usb_compatible_id = {
		.wLength = sizeof(struct msosv2_compatible_id),
		.wDescriptorType = MS_OS_20_FEATURE_COMPATIBLE_ID,
		.CompatibleID = {COMPATIBLE_ID_WINUSB},
	},
	.gs_usb_guids_property = {
		.wLength = sizeof(struct msosv2_guids_property),
		.wDescriptorType = MS_OS_20_FEATURE_REG_PROPERTY,
		.wPropertyDataType = MS_OS_20_PROPERTY_DATA_REG_MULTI_SZ,
		.wPropertyNameLength = 42,
		.PropertyName = {DEVICE_INTERFACE_GUIDS_PROPERTY_NAME},
		.wPropertyDataLength = 80,
		.bPropertyData = {CANNECTIVITY_GS_USB_DEVICE_INTERFACE_GUID},
	},
	.gs_usb_vendor_revision = {
		.wLength = sizeof(struct msosv2_vendor_revision),
		.wDescriptorType = MS_OS_20_FEATURE_VENDOR_REVISION,
		.VendorRevision = 1U,
	},
};

struct usb_bos_capability_msosv2 {
	struct usb_bos_platform_descriptor platform;
	struct usb_bos_capability_msos cap;
} __packed;


static struct usb_bos_capability_msosv2 bos_cap_msosv2 = {
	.platform = {
		.bLength = sizeof(struct usb_bos_capability_msosv2),
		.bDescriptorType = USB_DESC_DEVICE_CAPABILITY,
		.bDevCapabilityType = USB_BOS_CAPABILITY_PLATFORM,
		.bReserved = 0,
		.PlatformCapabilityUUID = {
			/* MS OS 2.0 Platform Capability ID: D8DD60DF-4589-4CC7-9CD2-659D9E648A9F */
			0xDF, 0x60, 0xDD, 0xD8,
			0x89, 0x45,
			0xC7, 0x4C,
			0x9C, 0xD2,
			0x65, 0x9D, 0x9E, 0x64, 0x8A, 0x9F,
		},
	},
	.cap = {
		/* Windows version (8.1) (0x06030000) */
		.dwWindowsVersion = sys_cpu_to_le32(0x06030000),
		.wMSOSDescriptorSetTotalLength =
			sys_cpu_to_le16(sizeof(struct cannectivity_msosv2_descriptor)),
		.bMS_VendorCode = GS_USB_MS_VENDORCODE,
		.bAltEnumCode = 0x00
	},
};

static int vendorcode_handler(const struct usbd_context *const ctx,
			      const struct usb_setup_packet *const setup,
			      struct net_buf *const buf)
{
	size_t len = bos_cap_msosv2.cap.wMSOSDescriptorSetTotalLength;

	if (setup->bRequest == GS_USB_MS_VENDORCODE &&
	    setup->wIndex == MS_OS_20_DESCRIPTOR_INDEX) {
		net_buf_add_mem(buf, &msosv2_descriptor,
				MIN(net_buf_tailroom(buf), len));

		return 0;
	}

	return -ENOTSUP;
}

USBD_DESC_BOS_VREQ_DEFINE(msosv2, sizeof(bos_cap_msosv2), &bos_cap_msosv2,
			  GS_USB_MS_VENDORCODE, vendorcode_handler, NULL);

struct usbd_context *usbd_setup_device(usbd_msg_cb_t msg_cb)
{
	int err;

	err = usbd_add_descriptor(&usbd_ctx, &lang);
	if (err) {
		LOG_ERR("Failed to initialize language descriptor (%d)", err);
		return NULL;
	}

	err = usbd_add_descriptor(&usbd_ctx, &mfr);
	if (err) {
		LOG_ERR("Failed to initialize manufacturer descriptor (%d)", err);
		return NULL;
		}

	err = usbd_add_descriptor(&usbd_ctx, &product);
	if (err) {
		LOG_ERR("Failed to initialize product descriptor (%d)", err);
		return NULL;
	}

	err = usbd_add_descriptor(&usbd_ctx, &sn);
	if (err) {
		LOG_ERR("Failed to initialize SN descriptor (%d)", err);
		return NULL;
	}

	err = usbd_add_configuration(&usbd_ctx, USBD_SPEED_FS,
				     &fs_config);
	if (err) {
		LOG_ERR("Failed to add Full-Speed configuration");
		return NULL;
	}

	err = usbd_register_all_classes(&usbd_ctx, USBD_SPEED_FS, 1, blocklist);
	if (err) {
		LOG_ERR("FS: Failed to add register classes");
		return NULL;
	}

	usbd_device_set_code_triple(&usbd_ctx, USBD_SPEED_FS,
				    USB_BCC_MISCELLANEOUS, 0x02, 0x01);
	usbd_self_powered(&usbd_ctx, attributes & USB_SCD_SELF_POWERED);

	if (msg_cb) {
		err = usbd_msg_register_cb(&usbd_ctx, msg_cb);
		if (err) {
			LOG_ERR("Failed to register message callback");
			return NULL;
		}
	}

	err = usbd_device_set_bcd_usb(&usbd_ctx, USBD_SPEED_FS, USB_SRN_2_0_1);
	if (err) {
		LOG_ERR("failed to set full-speed bcdUSB (err %d)", err);
		return NULL;
	}

	err = usbd_add_descriptor(&usbd_ctx, &usbext);
	if (err) {
		LOG_ERR("Failed to add USB 2.0 Extension Descriptor");
		return NULL;
	}

	err = usbd_add_descriptor(&usbd_ctx, &msosv2);
	if (err) {
		LOG_ERR("failed to add Microsoft OS 2.0 descriptor (err %d)", err);
		return NULL;
	}

	return &usbd_ctx;
}

struct usbd_context *usbd_init_device(usbd_msg_cb_t msg_cb)
{
	struct usbd_context *ctx;
	int err;

	ctx = usbd_setup_device(msg_cb);
	if (!ctx)
		return NULL;

	err = usbd_init(ctx);
	if (err) {
		LOG_ERR("Failed to initialize device support");
		return NULL;
	}

	return ctx;
}
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

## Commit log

2026-01-24 Revisit 3D models
    [can.kicad_sch, serial.kicad_sch, sertest-ng.kicad_pcb]
2026-01-26 Fix Dual LED footprint issue
    [can.kicad_sch, serial.kicad_sch, sertest-ng.kicad_pcb]
2026-01-27 Replace JLCPCB part to fit footprint
    [sertest-ng.kicad_pcb, usbserial.kicad_sch]
2026-01-31 Add enclosure
    [sertest-ng.FCStd]
2026-03-16 Update STM32CubeMX project
2026-03-16 Swap USART1 RX/TX
    [sertest-ng.kicad_pcb, sertest-ng.kicad_sch]
2026-03-16 Rework serial from DTE to DCE
    [serial.kicad_sch, sertest-ng.kicad_pcb]
2026-03-16 Fix USB signal swap
    [sertest-ng.kicad_pcb, sertest-ng.kicad_sch]
2026-03-16 Add USB termination resistors
    [can.kicad_sch, sertest-ng.kicad_pcb, sertest-ng.kicad_sch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]
2026-03-16 Add BOOT0 support
    [sertest-ng.kicad_pcb, sertest-ng.kicad_sch]
2026-03-21 Add second EEPROM
    [sertest-ng.kicad_pcb, sertest-ng.kicad_sch]
2026-03-22 Bump to v0.2
    [can.kicad_sch, serial.kicad_sch, sertest-ng.kicad_pcb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]
2026-04-01 zephyr: Switch to devel/sertest-ng

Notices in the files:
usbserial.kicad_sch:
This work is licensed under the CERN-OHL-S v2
